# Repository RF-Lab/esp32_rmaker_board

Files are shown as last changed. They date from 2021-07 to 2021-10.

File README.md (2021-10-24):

# esp32_rmaker_board

Rmaker is open source [Rain Maker](https://rainmaker.espressif.com/) ready home automation controller. This board includes:

* [ESP32 DevKit](https://www.aliexpress.com/wholesale?catId=0&initiative_id=SB_20210715114037&SearchText=esp32).
* 6 buffered open collector interfaces for switch control.
* 3 pull-up input interfaces for push buttons or dry electrode or other 1-pin digital sensors (like Hall-sensor).
* Onboard DHT-22 thermometer.
* 1 pre-conditioned ADC input for water pressure or similar sensor.
* Firmware examples based on Espressif code can be found [Here](https://github.com/RF-Lab/esp32_rmaker_sw)

# esp32_rmaker_board installed to Legrand LX3





# esp32_rmaker_board installed to Legrand Plexo









# Schematic


# PCB


# [Rain Maker](https://rainmaker.espressif.com/) Android app interface example


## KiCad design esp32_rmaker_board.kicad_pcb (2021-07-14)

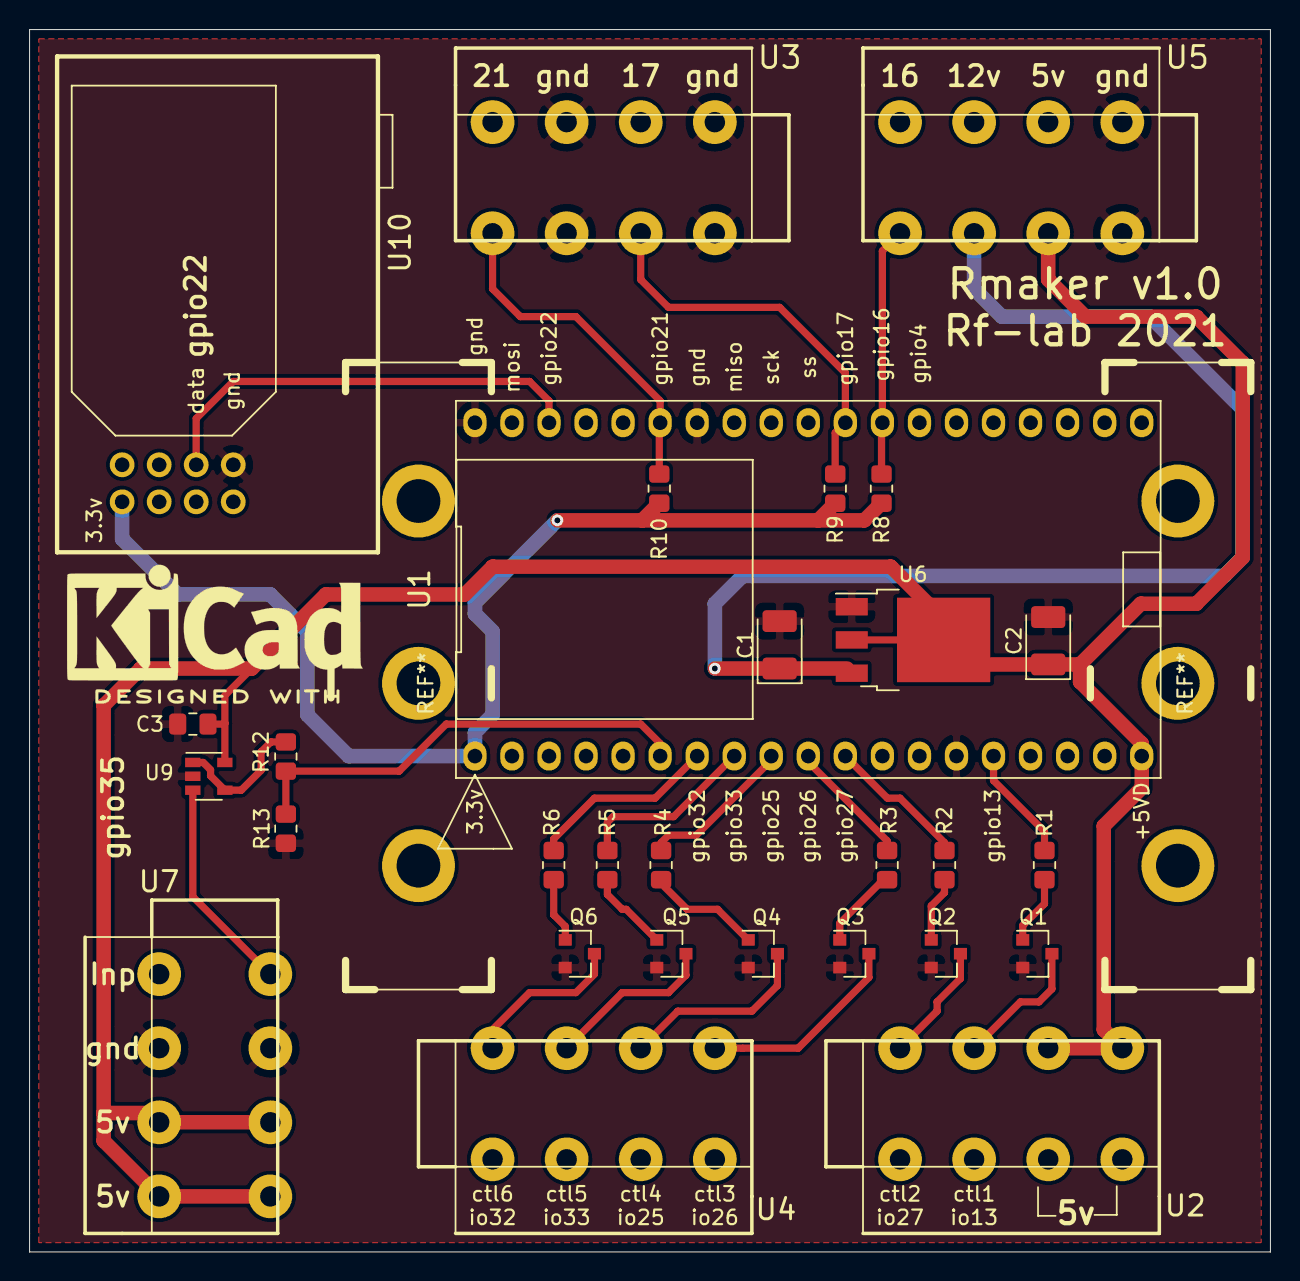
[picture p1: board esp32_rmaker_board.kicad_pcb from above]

Board: 2 copper layers, 85.1 x 83.8 mm, 29 parts (0 on the bottom side), 29 nets.

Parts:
C1, C2: CP1; CP_EIA-3528-21_Kemet-B_Pad1.50x2.35mm_HandSolder
C3: 0.1; C_0805_2012Metric_Pad1.18x1.45mm_HandSolder
Q1, Q2, Q3, Q4, Q5, Q6: BC817; SOT-23
R1, R2, R3, R4, R5, R6, R13: 1k; R_0805_2012Metric_Pad1.20x1.40mm_HandSolder
R8, R9, R10: 10k; R_0805_2012Metric_Pad1.20x1.40mm_HandSolder
R12: 4k; R_0805_2012Metric_Pad1.20x1.40mm_HandSolder
U1: ESP32-DevKitC-MCU_Espressif; DIP-38_W22.86m_P2.54mm_ESP32_DevKitC
U2, U3, U4, U5, U7: DG142V-5.08-4
U6: LM1117-5.0; TO-252-3_TabPin2
U9: OPA340NA; SOT-23-5
U10: DHT22

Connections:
3v3: R8.2, R9.2, R10.2, U1.1, U10.1
5v: C2.1, C3.1, U1.19, U2.5, U2.6, U5.7, U6.2, U7.3, U7.4, U7.5, U7.6, U9.5
GND: C1.2, C2.2, C3.2, Q1.2, Q2.2, Q3.2, Q4.2, Q5.2, Q6.2, R13.1, U1.14, U1.32, U1.38, U3.1, U3.3, U3.6, U3.8, U5.1, U5.8, U6.1, U7.2, U7.7, U9.2, U10.5
unnamed: Q1.1, R1.1
unnamed: Q2.1, R2.1
unnamed: Q3.1, R3.1
unnamed: Q4.1, R4.1
unnamed: Q5.1, R5.1
unnamed: Q6.1, R6.1
unnamed: R12.2, U9.1, U9.4
adcInp: U7.8, U9.3
ext_6.5_12v: C1.1, U5.6, U6.3
gpio13: R1.2, U1.15
gpio16: R8.1, U1.27, U5.5
gpio17: R9.1, U1.28, U3.7
gpio21: R10.1, U1.33, U3.5
gpio22: U1.36, U10.6
gpio25: R4.2, U1.9
gpio26: R3.2, U1.10
gpio27: R2.2, U1.11
gpio32: R6.2, U1.7
gpio33: R5.2, U1.8
gpio35: R12.1, R13.2, U1.6
outCtl1: Q1.3, U2.7
outCtl2: Q2.3, U2.8
outCtl3: Q3.3, U4.5
outCtl4: Q4.3, U4.6
outCtl5: Q5.3, U4.7
outCtl6: Q6.3, U4.8
